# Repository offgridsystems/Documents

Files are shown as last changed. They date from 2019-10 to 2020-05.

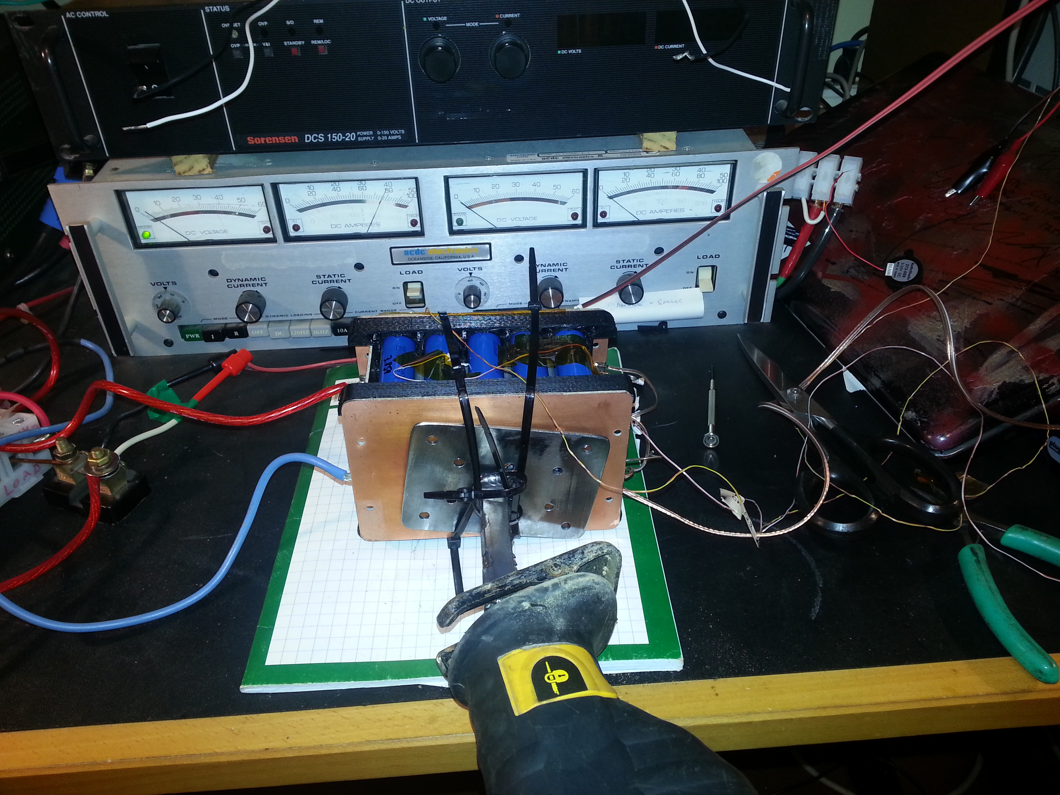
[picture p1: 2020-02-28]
shake test setup.jpg

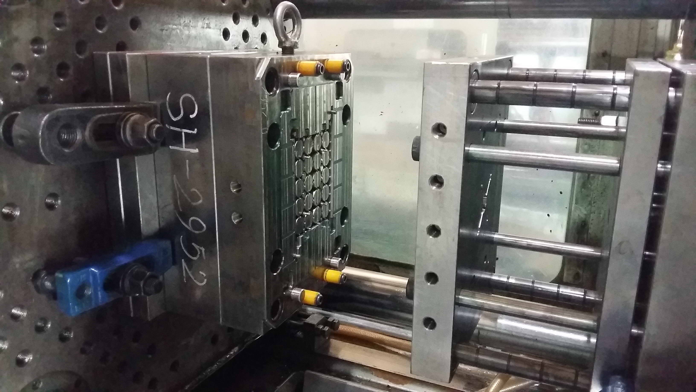
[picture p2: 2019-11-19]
DK battery cell holder - OSHW/20160715_152525.jpg

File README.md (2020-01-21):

# DKblock documents -  
Here is the DK website for more information: https://dkblock922508958.wordpress.com 

Here is the ebay store for some parts. Let me know at the "Contact" tab of Wordpress (or ebay) if there is something else you would like.
https://www.ebay.com/sch/i.html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

All documents can be opened in OpenOffice format or Adobe Acrobat Reader. Some drawing files are in Alibre Design (for example AD_DRW extension). Please note that if your CAD program cannot read these files, not to worry because most CAD programs can output formats that can be read by other CAD programs, so please ask if you would like another format, we will try to accomodate.

blocks connected2

All DKblock software and hardware is released as open source hardware (OSHW) as defined by the OSHWA: https://www.oshwa.org/definition/ and under the JSON license defined at https://www.json.org/license.html

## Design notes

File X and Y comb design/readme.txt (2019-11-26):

This is a 6 finger design that can be printed using any 3D printer in practically any non-conductive material. It will be used for both X and Y axis for building DK packs. Picture on how to use the combs is in the DKblock assembly sheet at https://github.com/offgridsystems/Documents 

file:///C:/Users/Tim%20Economu/Dropbox/DKblock/Images/2016-07-06%2015.13.45.jpg

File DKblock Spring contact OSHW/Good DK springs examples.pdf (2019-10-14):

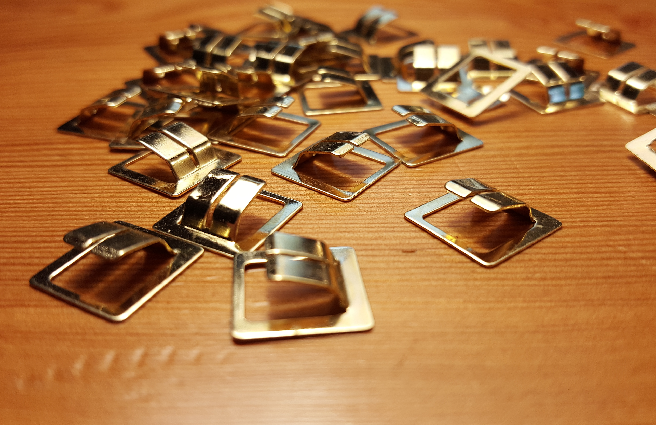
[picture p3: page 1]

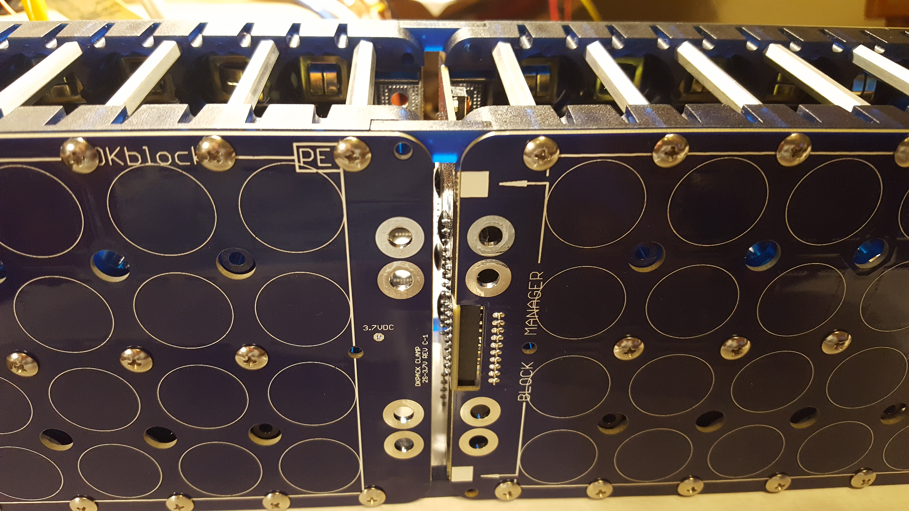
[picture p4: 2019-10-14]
DK battery cell holder - OSHW/more dk 001.jpg

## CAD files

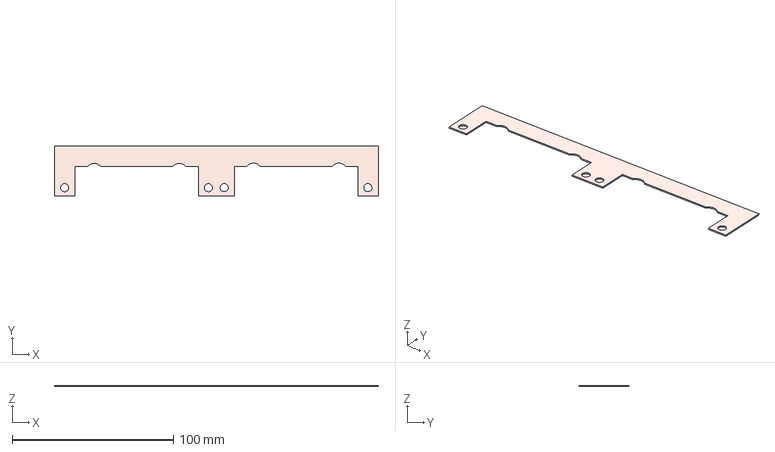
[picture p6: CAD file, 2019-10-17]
Busbars/Copper BusBar - 3 Par Blocks v6.step
201.1 x 30.9 x 0.813 mm

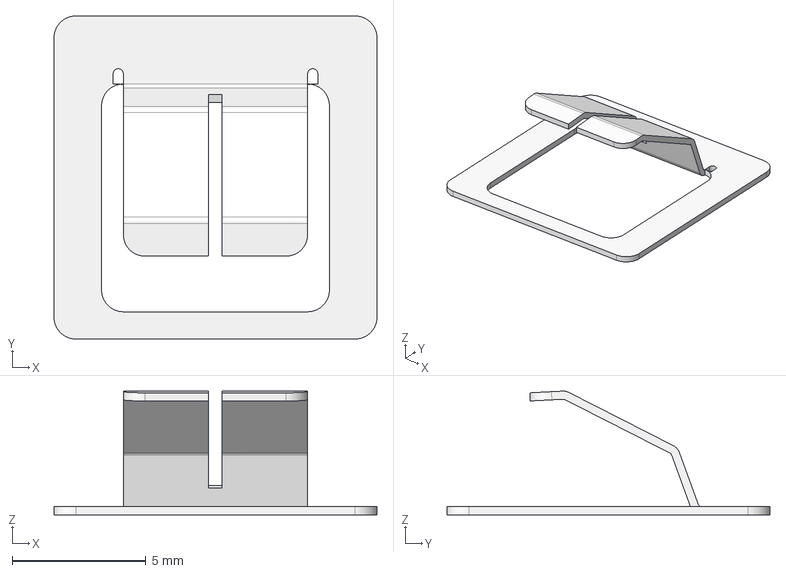
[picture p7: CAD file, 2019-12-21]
DKblock Spring contact OSHW/DK spring finger rev B.stp
12.1 x 12.1 x 4.62 mm

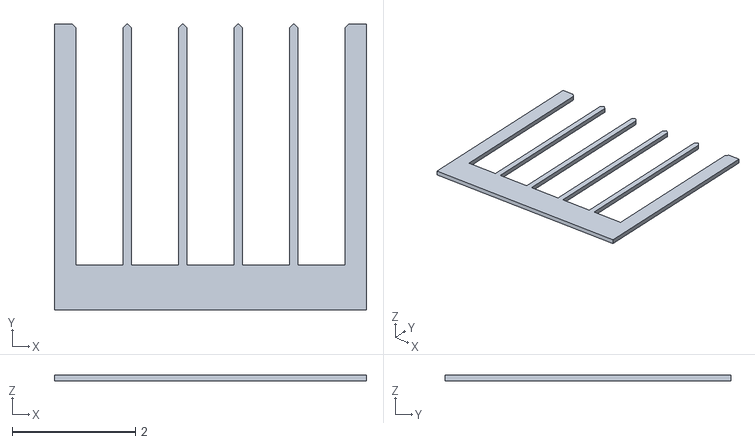
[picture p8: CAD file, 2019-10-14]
X and Y comb design/battery cell comb.stl
5.06 x 4.64 x 0.1

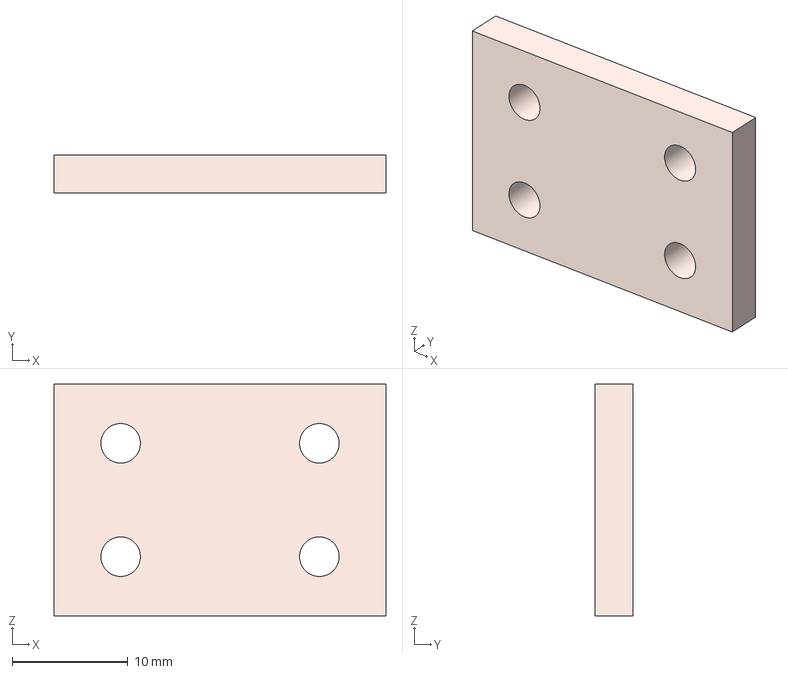
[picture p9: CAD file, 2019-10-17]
Busbars/Copper Busbar - Series Link v5.step
28.6 x 3.30 x 20.0 mm

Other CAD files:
Busbars/Copper BusBar - 3 Par Blocks v6.f3z
Busbars/Copper Busbar - Series Link v5.f3d

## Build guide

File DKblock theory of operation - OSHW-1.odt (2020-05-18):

Dkblock – Theory of operation (first cut) 5.9.2020

Block Manager:

There is a Teensy (arduino type) microcomputer dedicated to each block, and it's job is to wake up every minute, and/or wake up when it senses the RF signal from the

supervisor, and begin taking the vital signs of the block. It measures the cell voltages, and cell temperatures, and ambient temp of the block and sends them via 2.4Ghz

ISM packets to the supervisor. The Block Manager senses whether the cells are charging or discharging, and when charging, will begin balancing at

around 4V per cell (programmable by the user in firmware) on increasing voltage and will stop balancing when the cells are equal OR when the voltage drops back below 4.0V or so. These are all programmable of

course, and depend on the cells you end up with. So read the data sheet carefully for those cells!

After the charge or discharge session is over, the blocks go back to sleep, and use under 300uA in sleep mode. If the blockvoltage drops below about 5V, the hardware low battery cutoff turns everything off, and there is maybe 150uA drain on the battery cells at that point.

Pack Supervisor:

The Pack Supervisor takes all the cell data and aggregates it and sends it out to the serial port. It also has settings for cell over/under voltage, over and under temperature, and ambient tempertuer, and will open the load or charge relays based on tthose settings.

Note that that Pack Supervisor also measures pack data like over-current, over and under temperature, and over and under voltage protection with dedicated charge and discharge relays that can control larger contactors if higher voltage or current is needed. The Pack Supervisor connects to the entire pack voltage using an isolated power supply and isolated connections for inputs like keyswitch and others. It is also designed to drive a 0-10V analog gauge to use for a “fuel tank” display.

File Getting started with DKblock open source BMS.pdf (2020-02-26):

Getting started with DKblock open source BMS | Doc Version V1.00 Feb 26, 2020

Thank you for purchasing genuine original DKblock parts from Offgrid Systems LLC, of Whidbey Island. We hope you will enjoy using and maybe extending the DKblock into new uses! This system was designed for the DIY'er or the engineer who wants a premium wireless BMS at a fraction of the cost.

There is a fairly complete build sheet for the DKblock at https://github.com/offgridsystems/Documents/blob/master/DKblock%20assembly%20sheet %20OSHW%20V28OCT18.pdf (or just search github for "offgrid" or "dkblock")

Also there are some build images on Wordpress at
https://dkblock922508958.wordpress.com

For flashing the Teesy microcontrollers on both the Block Manager and Pack Supervisors boards, you will need to make sure you have the latest Arduino IDE and the latest teensyduino code from PRJC.com at
https://www.pjrc.com/teensy/td_download.html

Please go to github for the latest code for both Block Manager and Pack Supervisor at https://github.com/offgridsystems/Firmware

For DKblock parts, search ebay for "dkblock" or go to https://www.ebay.com/sch/i.html?_from=R40&_trksid=m570.l1313&_nkw=dkblock&_sacat=0

There is a PCB Rev C Clamp Board mistake that needs to be fixed, please fix by drilling two holes as marked below (note that Rev D will have this fixed):

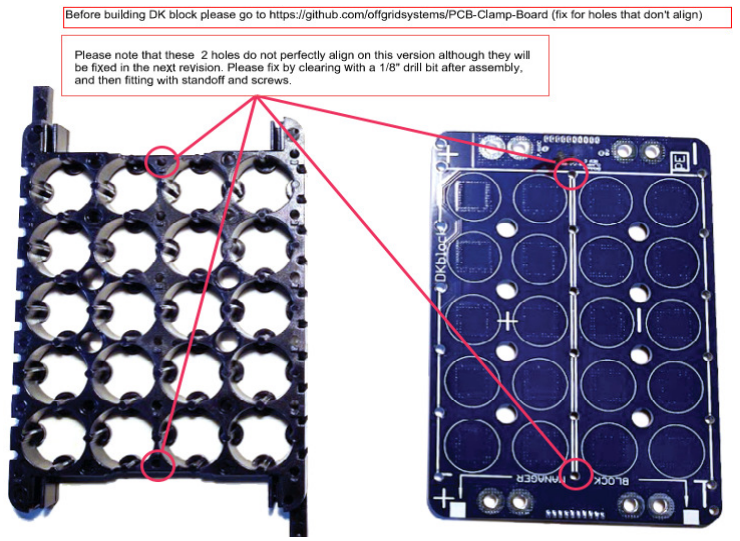
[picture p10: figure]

todo: Tim add overall block diagram on how the parts all fit together

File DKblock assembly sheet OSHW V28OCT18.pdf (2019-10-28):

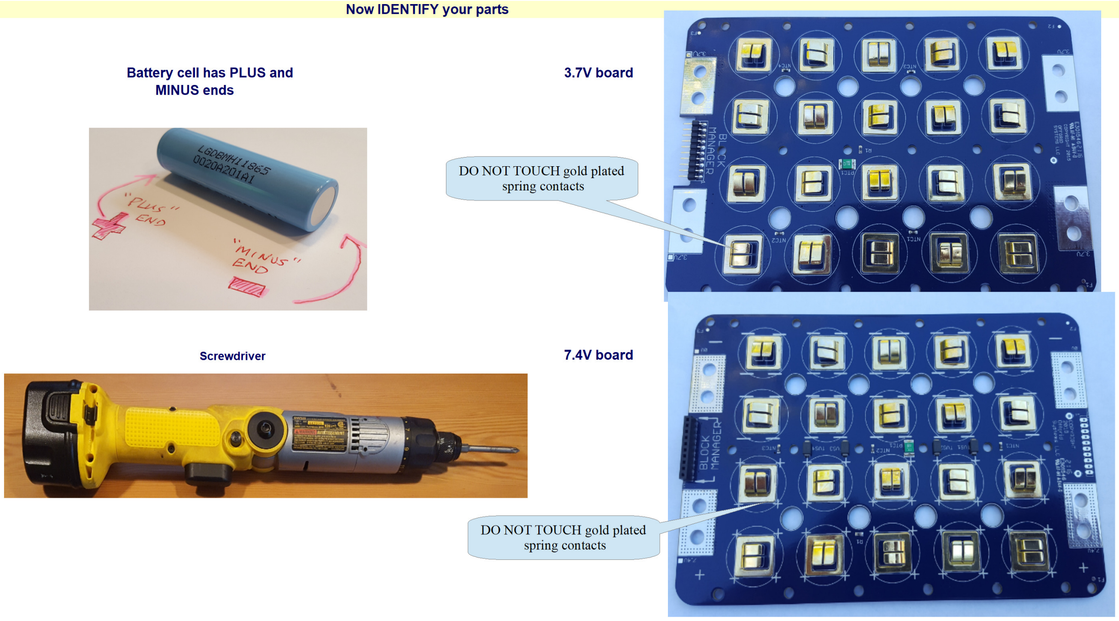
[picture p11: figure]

Page 1

Assembling the Dkblock battery block | Ver: Jul2016 Updated 1AUG2017, 28OCT2019

### First acquire parts and tools: 1. Lithium ion cells – 18650 size, 20 cells per 10S2P Dkblock 2. Dkblock clamp boards (one each 2S-3.7V and one each 2S-7.4-0V board) 3. Plastic cell holders – 2 each 4. Clean cotton gloves – one pair 5. Workbench with nonconducting surface 6. Standoff and screws

7. Dewalt DW920 with #1 philips bit or equivalent automatic screwdriver calibrated to 3.5 inch-pounds of torque

1

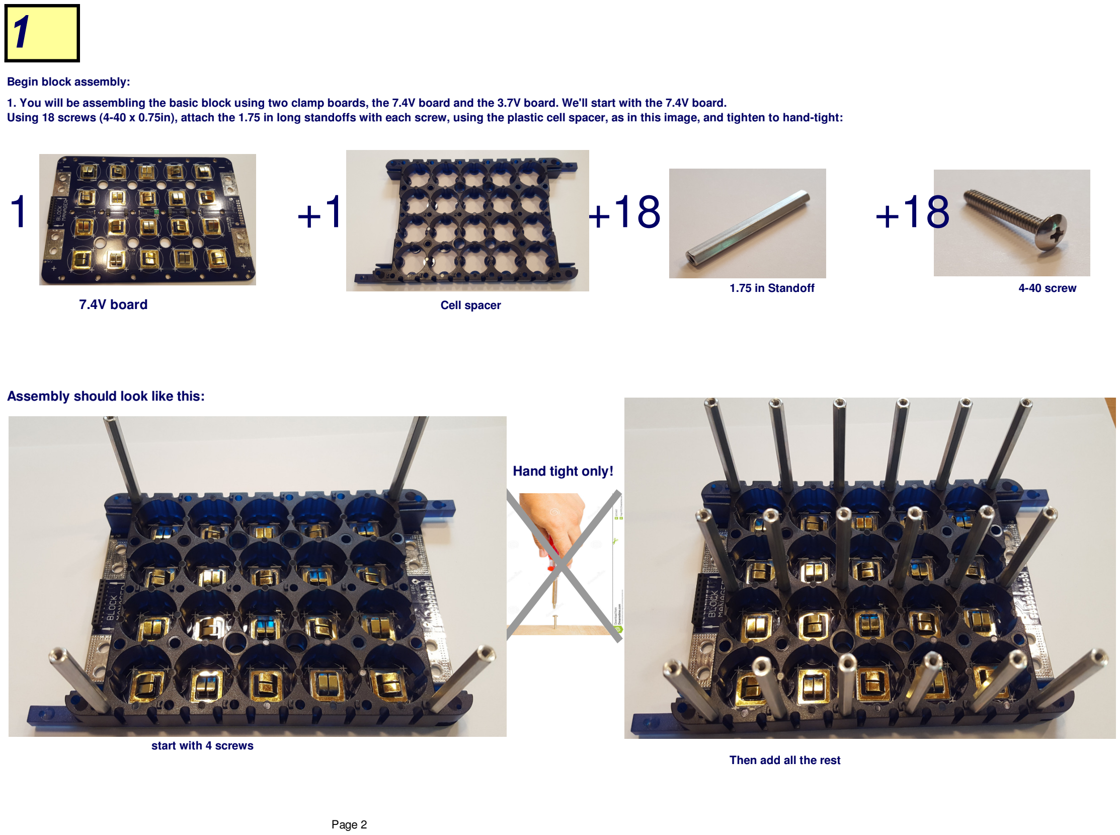
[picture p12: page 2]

Page 2

Begin block assembly:

1. You will be assembling the basic block using two clamp boards, the 7.4V board and the 3.7V board. We'll start with the 7.4V board.
Using 18 screws (4-40 x 0.75in), attach the 1.75 in long standoffs with each screw, using the plastic cell spacer, as in this image, and tighten to hand-tight:
1 | +1 | +18 | +18
1.75 in Standoff | 4-40 screw
7.4V board | Cell spacer

### Assembly should look like this:

### Hand tight only!

start with 4 screws
Then add all the rest

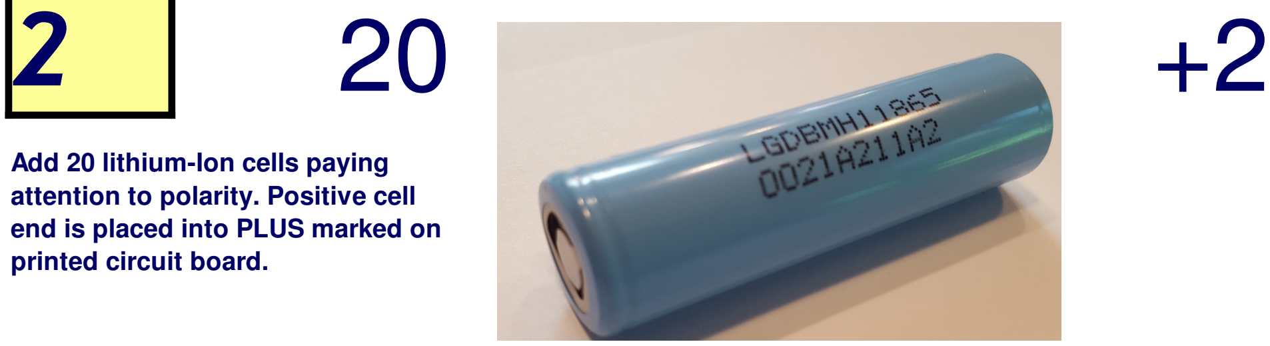
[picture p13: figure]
Add 20 lithium-Ion cells paying attention to polarity. Positive cell end is placed into PLUS marked on printed circuit board.
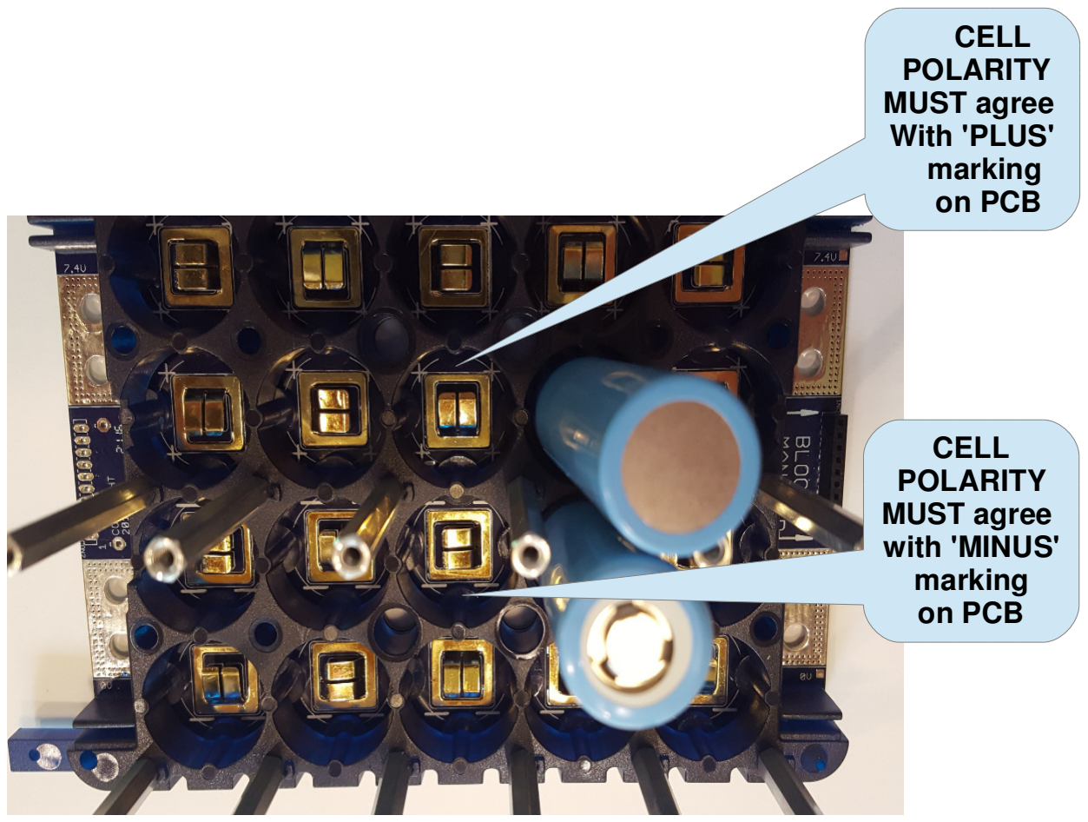
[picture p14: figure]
CELL POLARITY MUST agree With 'PLUS' marking on PCB; CELL POLARITY MUST agree with 'MINUS' marking on PCB

Page 3

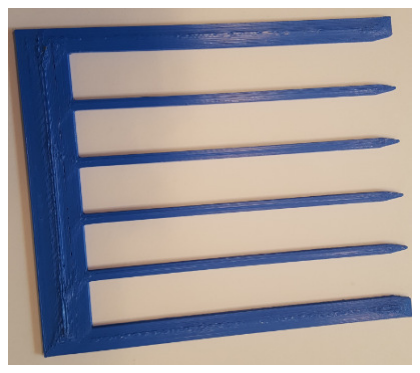
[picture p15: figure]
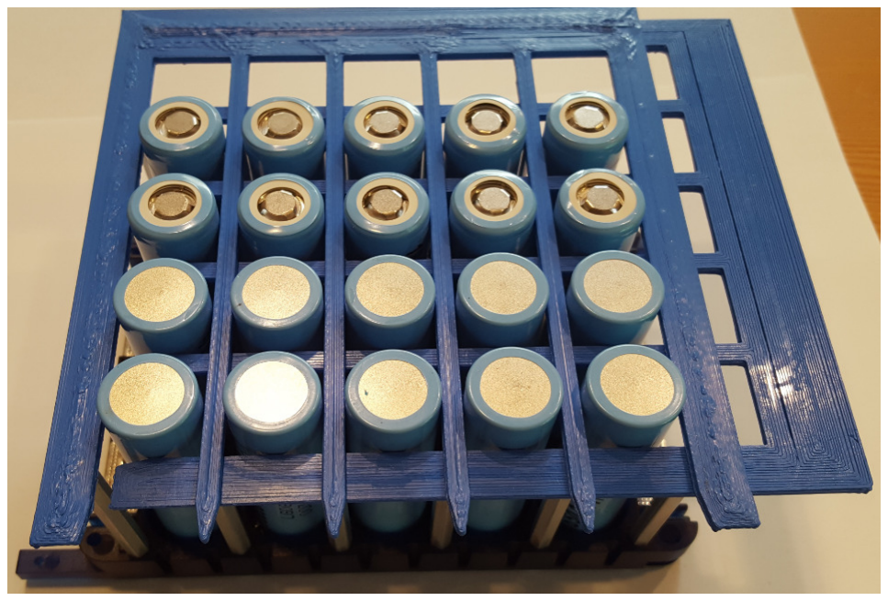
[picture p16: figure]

Place battery cells into place being very careful | Place cell array organizer over cells to prepare
with polarity. PLUS cell goes to plus on the | for the top cell spacer
printed circuit board

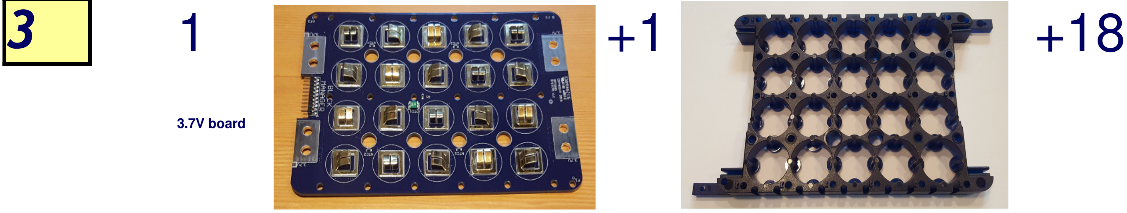
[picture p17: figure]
3.7V board
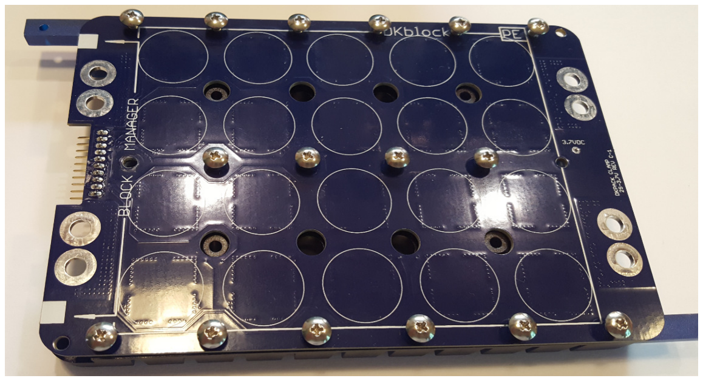
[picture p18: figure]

Page 4

Insert 18 screws into 3.7V board and cell spacer

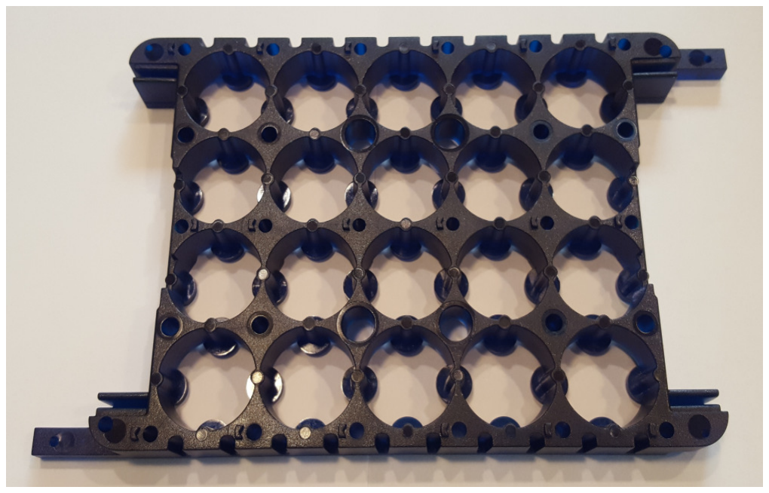
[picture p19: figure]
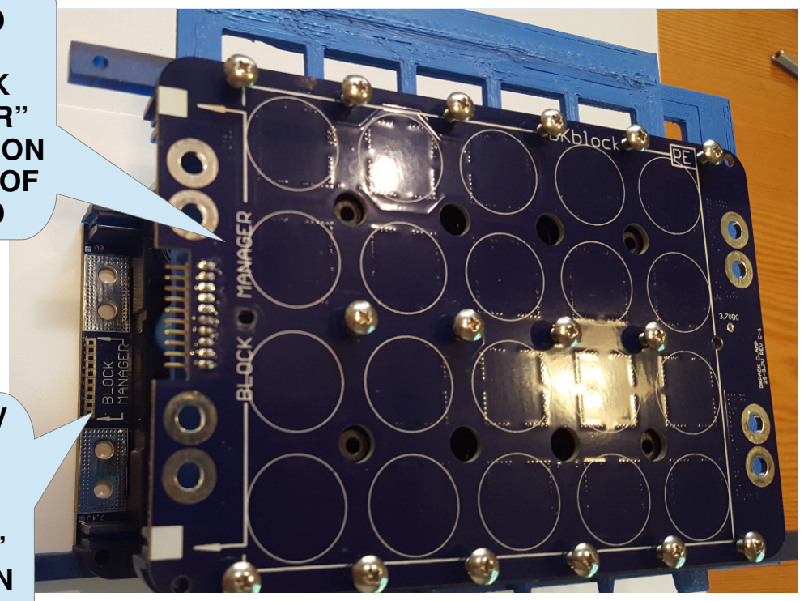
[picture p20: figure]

Place 3.7V board and cell spacer on

## ALIGN 3.7v BOARD WITH “BLOCK MANAGER” PRINTED ON THIS END OF BOARD

## ALIGN 7.4V BOARD WITH “BLOCK MANAGER” PRINTED ON THIS END OF BOARD

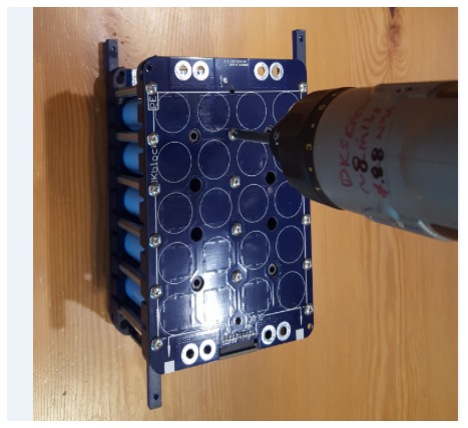
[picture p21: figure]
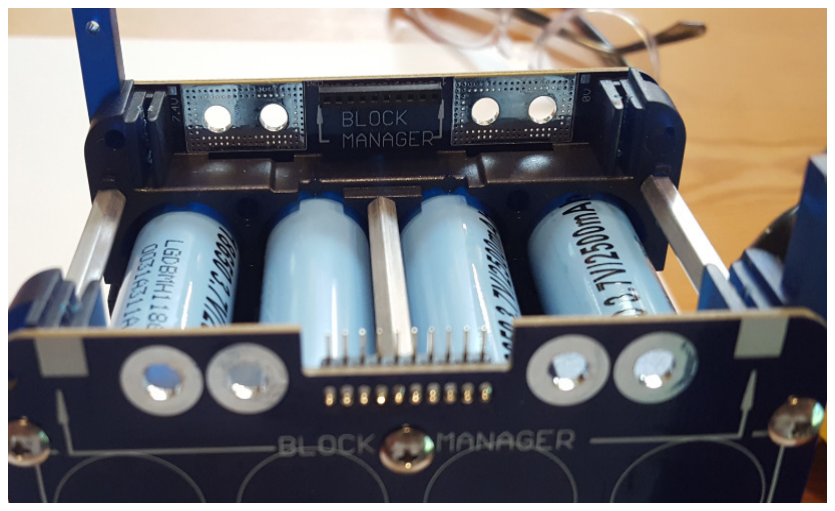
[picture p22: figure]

Page 5

4

Keep Dkblock on non-conductive surface for this operation

Tighten all screws on 3.7more V board to 3.5in-lbs | Tighten all screws on 7.4V board to 3.5in-lbs

Verify connectors on both boards are pointing up, and measure from plus (+) to minus (-) on 7.4V board, and verify voltage is at least 7.0VDC with the proper polarity.

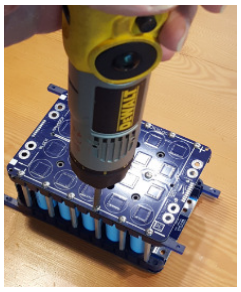
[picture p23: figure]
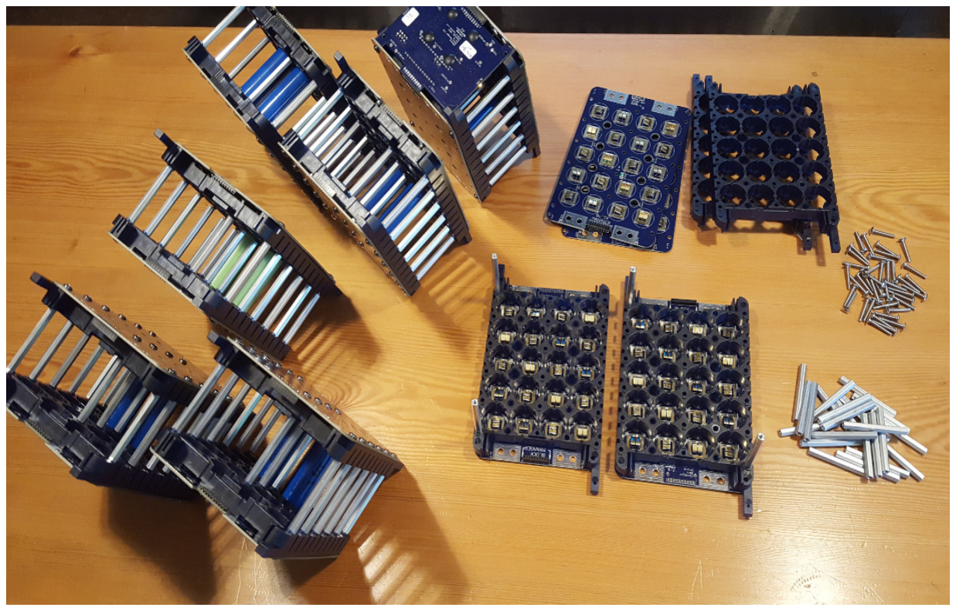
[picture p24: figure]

### Carefully place Dkblock in it's own box, or into a non-conductive anti-static bag

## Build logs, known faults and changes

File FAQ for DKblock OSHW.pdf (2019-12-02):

# Dkblock FAQ

What markets are the Dkblock designed for?
- One market is for electric vehicle (EV) systems from 24-72VDC and above. The largest systems built so far is a 60 block system with 20 blocks in series communicating to the Pack Supervisor, and the there are two more 20 block strings in parallel.
- Another market is home power-wall applications where energy density is valued over power density.
- Note that the Dkblock is better in terms of energy density over power density, noting that the 100 amps DC maximum block current helps explain why, expecially for larger packs.

What makes the Dkblock better than current battery packaging and management systems (BMS) on the market (as of Nov 2019)?
- You don't throw away your BMS when the batteries wear out! The Dkblock is reusable, simply change out the cells and populate with new cells. This is made possible because there is no welded battery contacts. The high current connections to the cells are made with gold plated spring contacts with a 10 amp rating.
- There is precise temperature measurement inside the block, 8 temperature sensor keep close tabs on what the cell temps actually are inside your pack.
- The Dkblock has wireless communications from blocks to the mother ship (Pack Supervisor) so there are no tiny wires running around the pack to break, making trouibleshooting and setup of the pack much faster and easier.
- Improved energy density over Lithium Iron Phosphate sytems on the order of 2X.

# Dkblocks FAQ page 2

Looking at the Dkblocks, I see that a system needs not only a few blocks, but also a Pack Supervisor board. Can I get away with just using the blocks alone, without the Pack Supervisor?

- The blocks are somewhat autonomous, they
will balance themselves to a point, they can carry the pack current, for a series parallel circuit for a pack,
and operate the cooling/warming fans inside each block.
- But a Pack Supervisor is required to do all the functions that all normal BMS's offer, such as overcurrent

protection, over and under temperature operation, over and under cell and pack voltage protections and

(eventually) communication to CANBUS or internet.

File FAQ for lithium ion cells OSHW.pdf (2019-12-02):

# Battery cell FAQ

How do I approach buying good quality new cells?
- Buy from a reputable seller so you do not get counterfeit cells.
- Buy reputable name brand, LG, Panasonic(Sanyo), Samsung, in that order are preferred. The cells are made in Japan or So Korea( both preferred) and China also ok, usually cheaper and slightly lower energy capacity.
- Do not buy any cell with 'fire' or 'vap' in the name. They will vaporize or catch fire (smiles).
- Look for higher C discharge rates on cells, 2C is standard, 3C is good. (DKblock is 100A max for 1 minute for 10 cells in parallel)
- Depending on quantities, plan on pricing from low $2's to high $3's for cells in the 3000-3500ma range with 3C and higher.
- There are not too many vendors to recommend, although Battery Bros do seem to stock genuine cells.

How do I improve the quality of cells I get from a good vendor?
- Ask for 1% or better voltage matching of the cells and also specify that all cells must come from the same lot.
- Ask for some sample cells to test
- Once the cells arrive, test the actual capacity in a BT-C3400 (picture below) or equivalent battery cell tester, to ensure you are getting what you paid for.

Can I use recycled cells?
- Yes, but it is important to match capacities, so it is important to test capacity of each battery and then use lots of similar capacities and voltage when building blocks. There are other considerations such as age and battery type, so it would be good to research what other cell aggregators are doing in this regard.

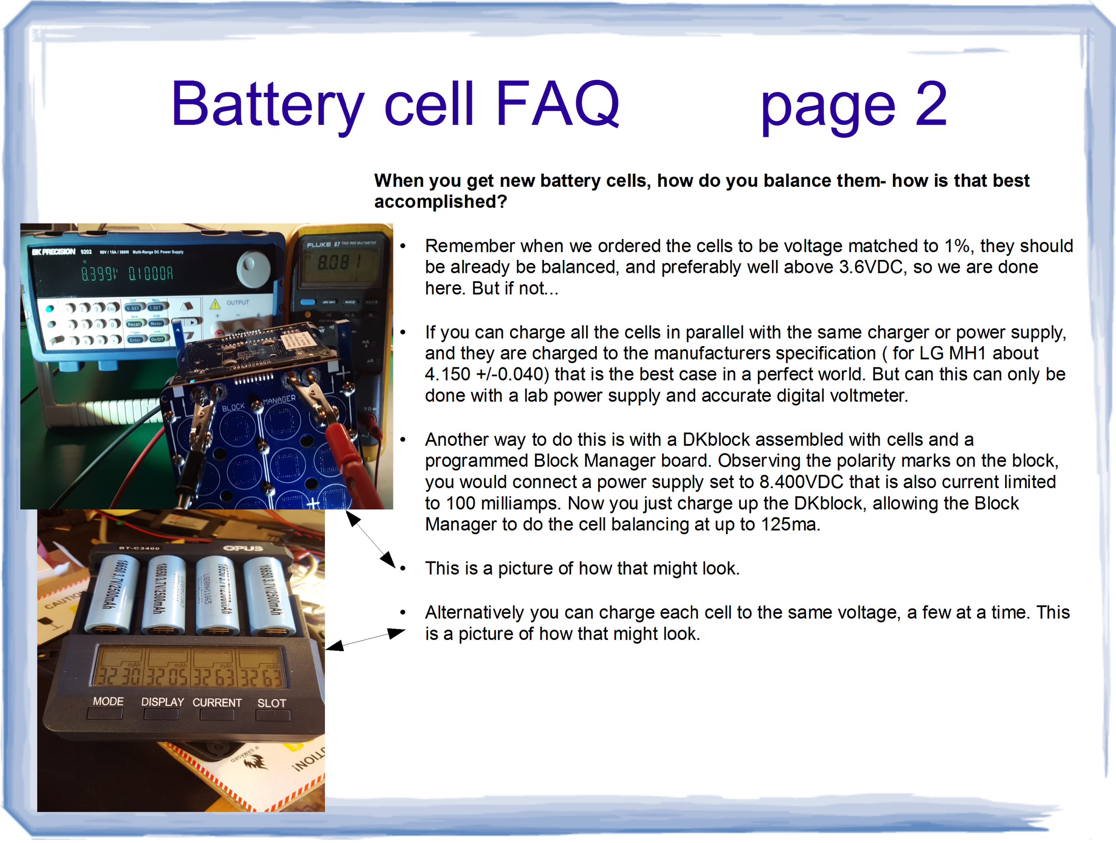
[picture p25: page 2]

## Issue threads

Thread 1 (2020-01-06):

any plans to support swappable cells?

allanlaal, 2020-01-06:

offgridsystems, 2020-01-06:
Yes the design of DKblock does allow you to swap cells when they wear out or go bad.
Also you can see the build process at https://dkblock922508958.wordpress.com/

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

offgridsystems, 2020-01-06:
If that answers your question Allen, I'll close the issue. Does that adequately answer your question?
Tim

allanlaal, 2020-01-09:
this type of replacement is satisfactory, but not quite the sitting on a rock in the middle of nowhere toolless (=multitool only) type of replacement

is it possible to add diodes for each cell, so that they wouldn't start welding themselves when the user mistakenly puts them in backwards. I've handled hundreds of cells and burned like 4 cheapo chinese charger doing this, its inevitable just by statistics :)

offgridsystems, 2020-01-09:
You can add diodes to each cell if you want, but no one building a battery will do that, losing 0.7Vx 4amp = 2.8watts at full load from each cell would be a tragedy of both heat buildup and energy loss, not to mention reduced voltage from the whole battery pack. Just don't put them in backwards, as you can see from my image above, it will look VERY obvious if you put them in backwards!
And can you do that sitting on a rock with a multitool, sure you can! They (like all high current battery connections) should be torqued properly, but if you break something way out in the boonies...hell yeah use whatever you have. And remember ... it's open source! You can change it to be whatever you want!
Tim

offgridsystems, 2020-01-10:
Closing now, since question about swappable cells was answered. The DKblock is expressly designed for the ability to swap bad or worn cells easily. Ideas are always welcome on how to improve the design for this purpose.
Tim

Closed 2020-01-10.

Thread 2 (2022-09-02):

Cell Holders?

BOOM-Mentoring, 2022-09-02:
Hello, your DK block shows cell-holders with pre-formed mounting holes. Where can i obtain these holders?

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

thejobbitt, 2022-09-02:
Hey BOOM,

Here is a link to our [ebay store](https://www.ebay.com/usr/economu).

Let me know if you run into any other questions. I know the repros are messy.

_theJobbitt

BOOM-Mentoring, 2022-10-11:
Thx!

________________________________
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

Closed 2022-09-02.

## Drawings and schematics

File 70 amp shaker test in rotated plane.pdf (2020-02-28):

### Sanyo 3400ma KS 2983 at 2C discharge

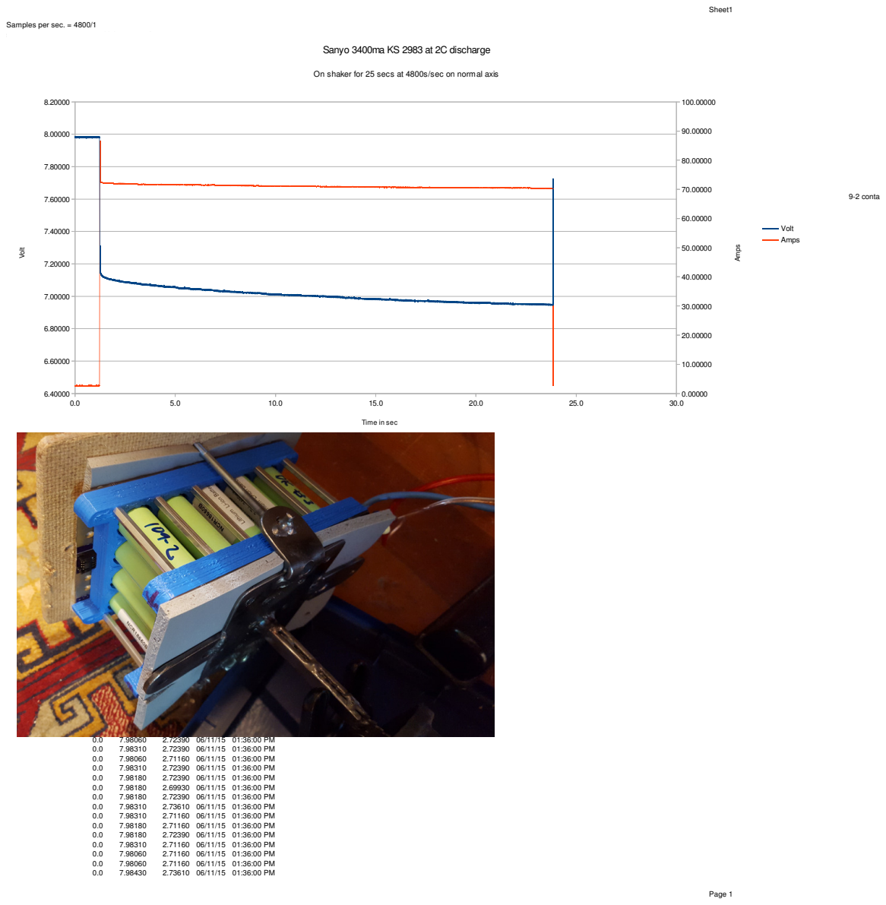
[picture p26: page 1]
Sheet1; sec; Volt; Amps; 9-2 conta; Volt Amps

Samples per sec. = 4800/1

On shaker for 25 secs at 4800s/sec on normal axis

Time in sec

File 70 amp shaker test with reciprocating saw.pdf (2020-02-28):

## Sanyo Panasonic 3400ma and Keystone 2983 at 2C on side axis

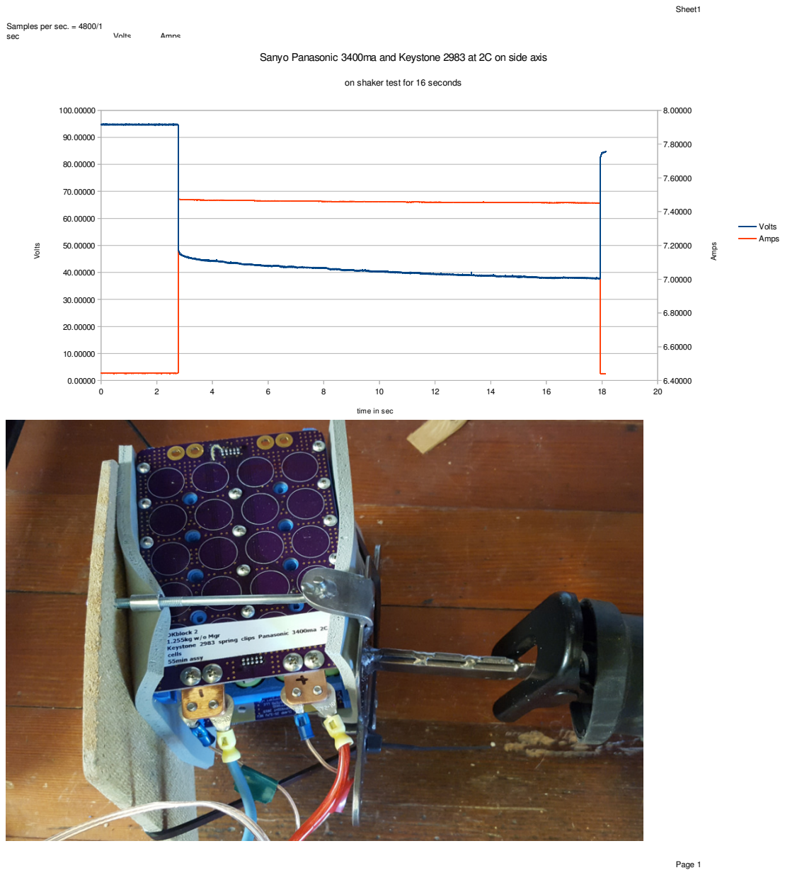
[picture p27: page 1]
Sheet1; sec; Volts; Amps

Samples per sec. = 4800/1

on shaker test for 16 seconds

time in sec

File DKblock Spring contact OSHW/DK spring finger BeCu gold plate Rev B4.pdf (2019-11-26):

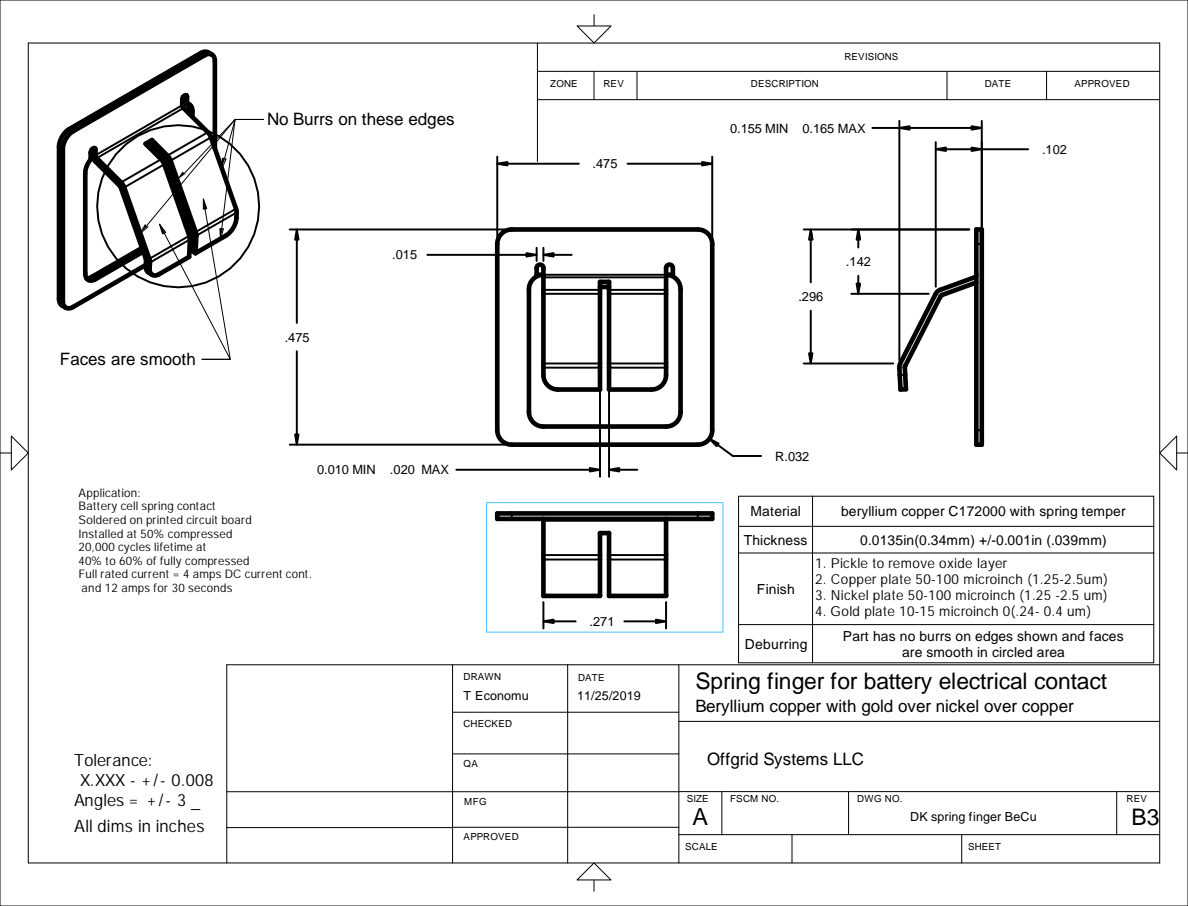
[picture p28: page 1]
0.155 MIN 0.165 MAX; 0.010 MIN; .020 MAX; SCALE; SHEET APPROVED

REVISIONS

ZONE | REV | DESCRIPTION | DATE | APPROVED

No Burrs on these edges

Faces are smooth

Application: Battery cell spring contact

Material | beryllium copper C172000 with spring temper

Soldered on printed circuit board
Installed at 50% compressed
20,000 cycles lifetime at
40% to 60% of fully compressed
Full rated current = 4 amps DC current cont. and 12 amps for 30 seconds

Thickness | 0.0135in(0.34mm) +/-0.001in (.039mm)
Finish | 1. Pickle to remove oxide layer 2. Copper plate 50-100 microinch (1.25-2.5um) 3. Nickel plate 50-100 microinch (1.25 -2.5 um) 4. Gold plate 10-15 microinch 0(.24- 0.4 um)

Deburring | Part has no burrs on edges shown and faces are smooth in circled area

DRAWN T Economu | DATE 11/25/2019 | Spring finger for battery electrical contact Beryllium copper with gold over nickel over copper

CHECKED

Tolerance:
X.XXX - +/- 0.008
Angles = + /- 3 _ All dims in inches

Offgrid Systems LLC

MFG | | SIZE A | FSCM NO. | DWG NO. DK spring finger BeCu | REV B3

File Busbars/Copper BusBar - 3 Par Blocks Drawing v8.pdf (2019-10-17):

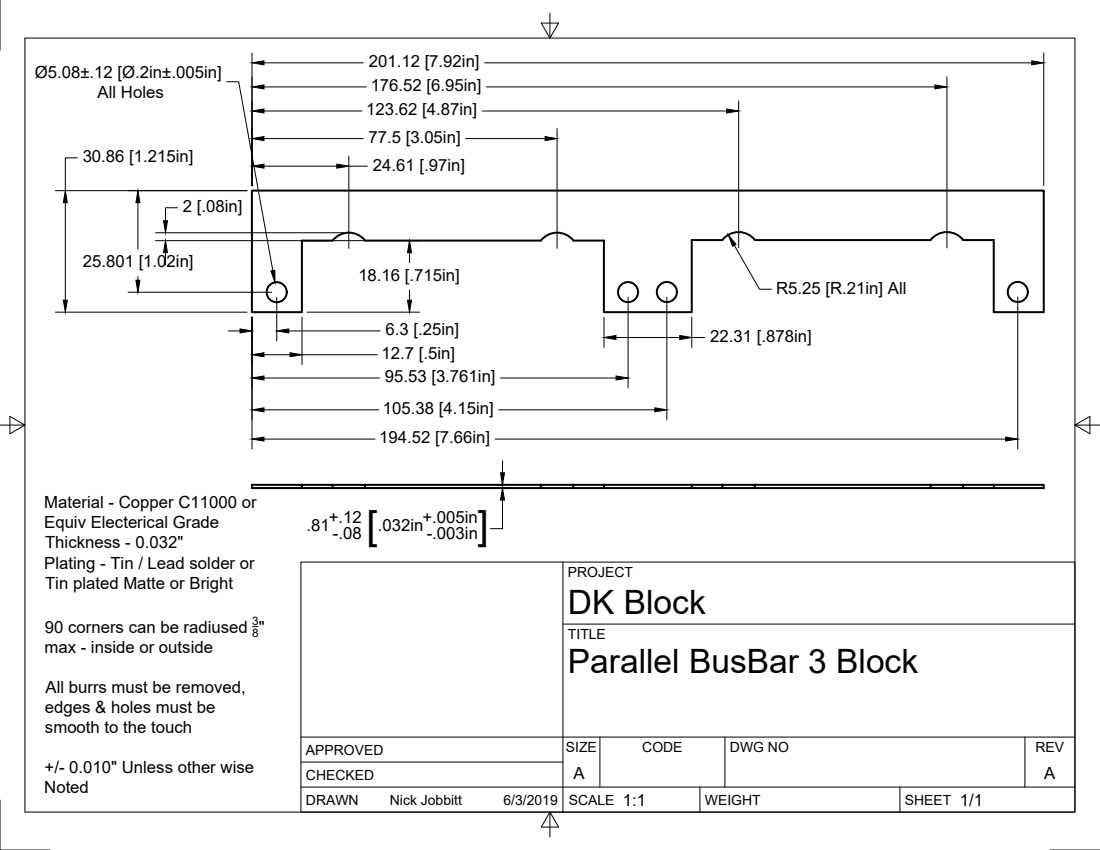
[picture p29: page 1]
SIZE; CODE; DWG NO; REV; Nick Jobbitt; Ø5.08±.12 [Ø.2in±.005in] All Holes; R5.25 [R.21in] All

-.003in] Material - Copper C11000 or
Equiv Electerical Grade
Thickness - 0.032"
Plating - Tin / Lead solder or
Tin plated Matte or Bright

PROJECT
DK Block
Parallel BusBar 3 Block

90 corners can be radiused 3
" max - inside or outside

All burrs must be removed,
edges & holes must be
smooth to the touch

+/- 0.010" Unless other wise
Noted

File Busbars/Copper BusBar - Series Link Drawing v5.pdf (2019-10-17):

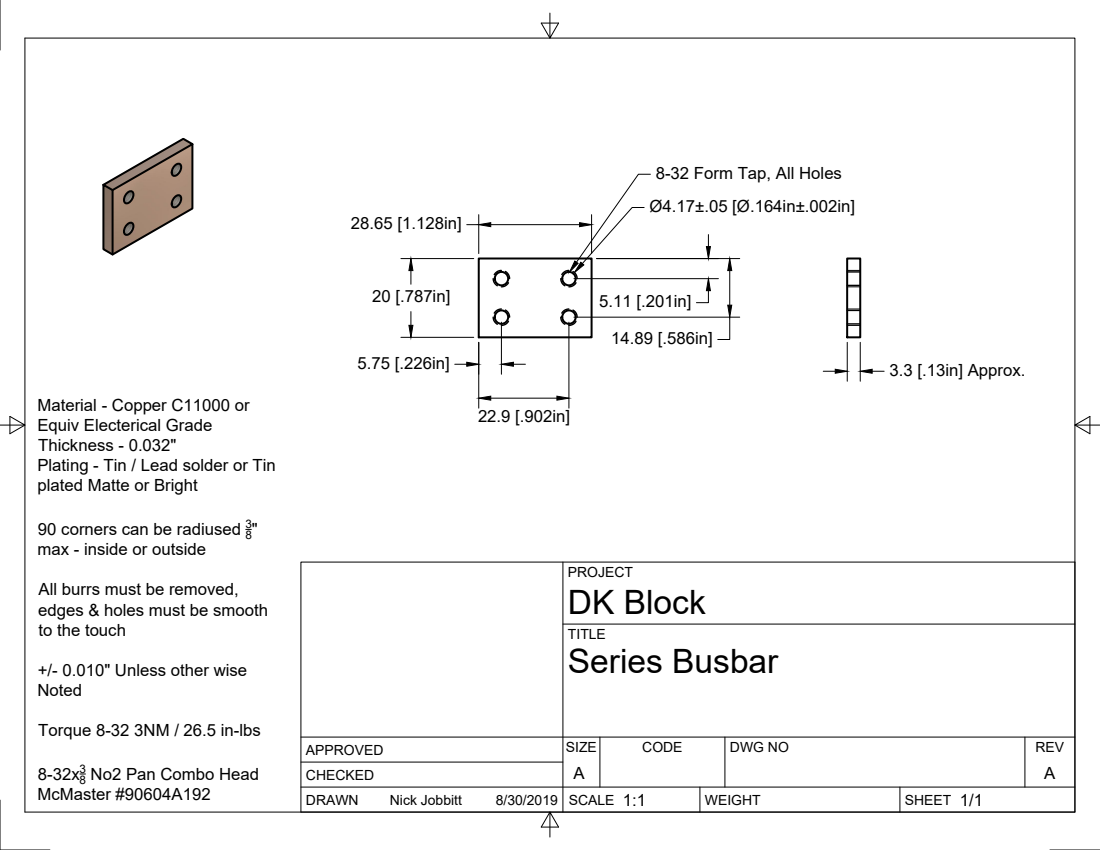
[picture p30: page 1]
SIZE; CODE; DWG NO; REV; Nick Jobbitt; DK Block; Series Busbar; 3.3 [.13in] Approx.; McMaster #90604A192

8-32 Form Tap, All Holes

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

90 corners can be radiused 3
" max - inside or outside

All burrs must be removed,
edges & holes must be smooth
to the touch

+/- 0.010" Unless other wise
Noted

Torque 8-32 3NM / 26.5 in-lbs

No2 Pan Combo Head

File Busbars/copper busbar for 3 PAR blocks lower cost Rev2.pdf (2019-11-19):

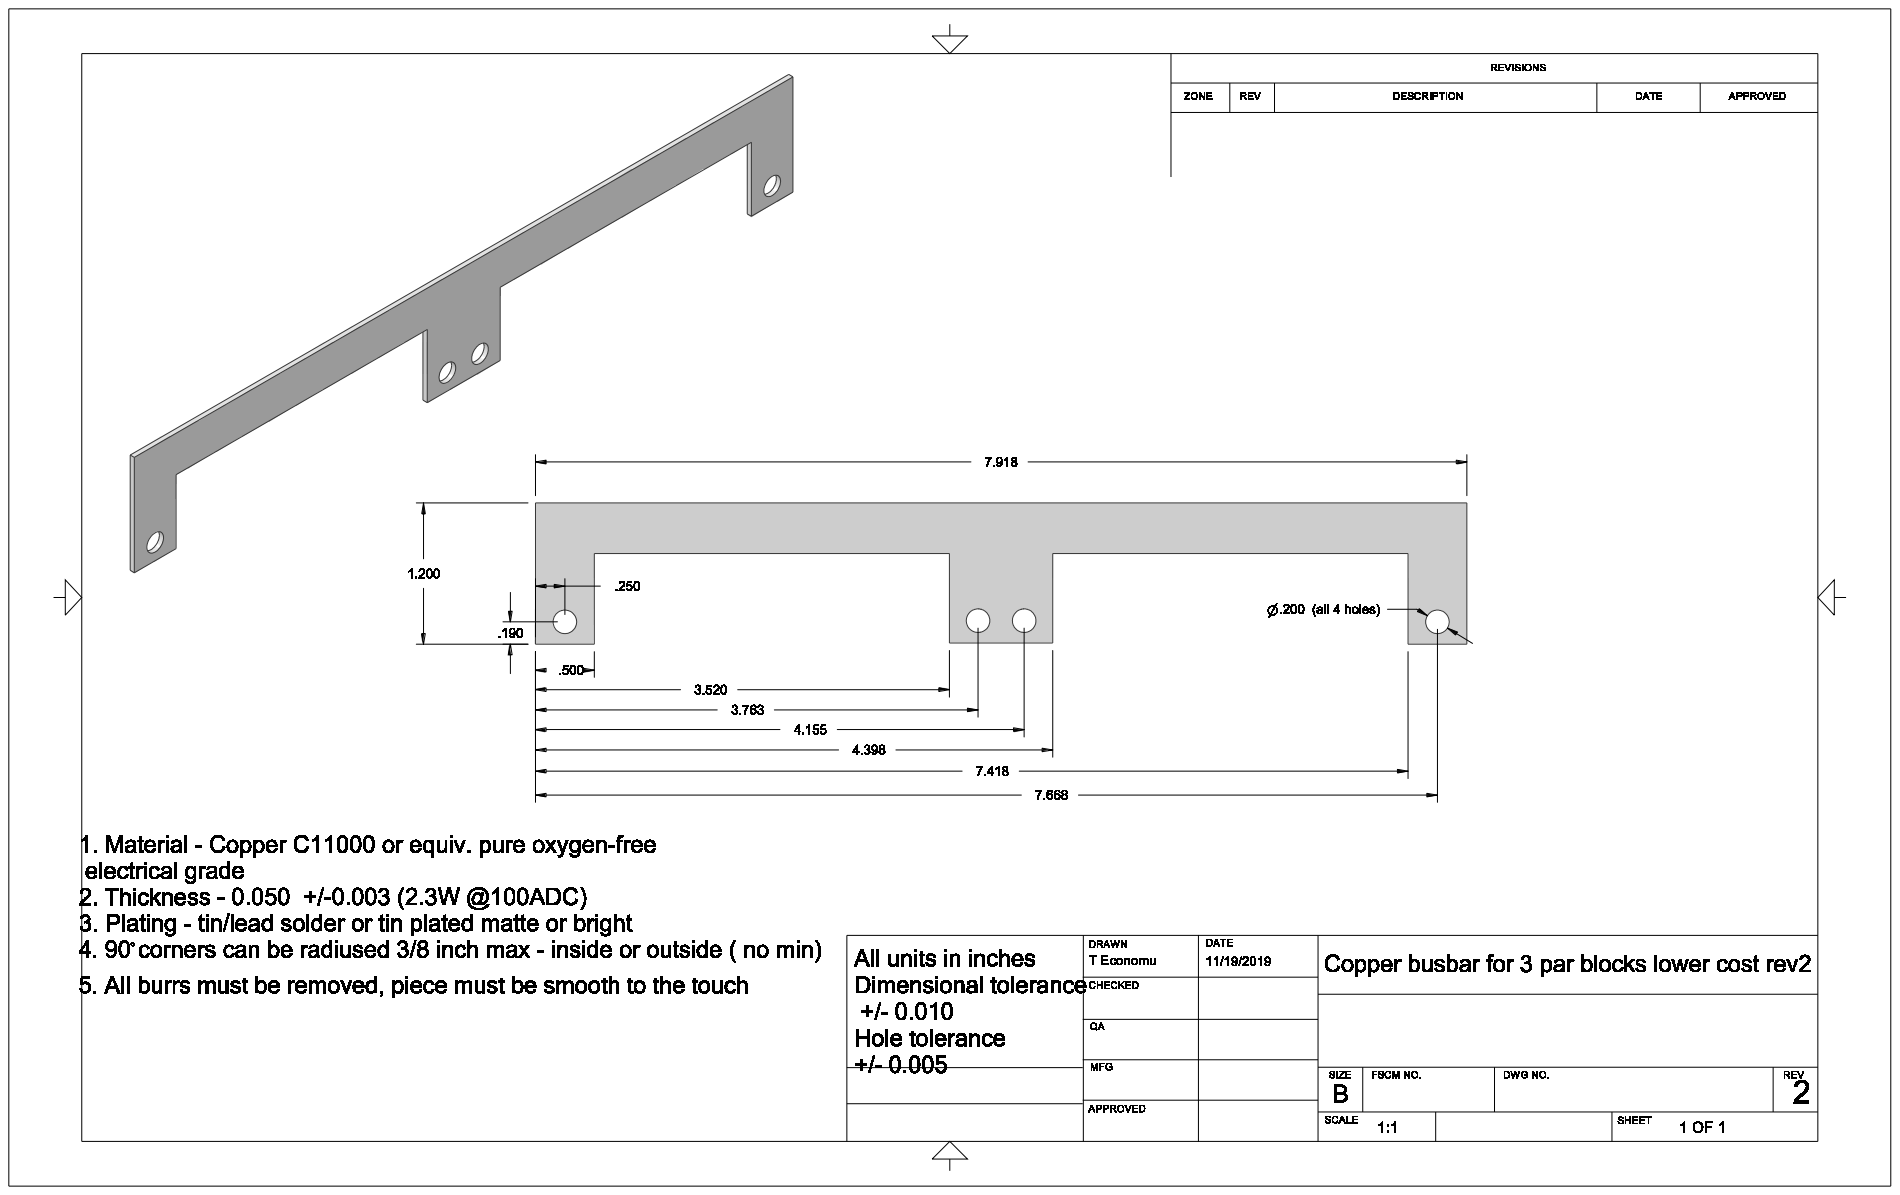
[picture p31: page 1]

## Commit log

2019-10-14 Initial Upload
    [Copper BusBar - 3 Par Blocks v5.f3z, Copper BusBar - 3 Par Blocks v5.step]
2019-10-14 Add files via upload
    These are the design files to make the plastic mold for the DK cell holder - 20 cell design
2019-10-17 RevA Increased Thickness
    Bar was too thin. Increased to .13 inches.
    [Copper Busbar - Series Link v5.f3d, Copper Busbar - Series Link v5.step]
2019-10-17 Added tolerances
    [Copper BusBar - 3 Par Blocks v6.f3z, Copper BusBar - 3 Par Blocks v6.step]
2019-11-19 Plastic mold
2019-11-19 Plastic injection mold
2019-11-26 Add correct material drawings
2019-12-06 Updated for max and continuous current ratings
2019-12-06 Updated with maximum and continuous current ratings
2019-12-06 Update max and cont current ratings
2019-12-06 added max and continuous current rating
2019-12-21 Step file for DK spring
    [DK spring finger rev B.stp]
2019-12-21 BOM for all DKblock incl Pack Supervisor - min system
